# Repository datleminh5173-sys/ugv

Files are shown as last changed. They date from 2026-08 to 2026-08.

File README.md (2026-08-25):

# 🚜 BỘ THIẾT KẾ ROBOT UGV ĐA TẢI TRỌNG (UGV ROBOT PLATFORMS)

Kho lưu trữ thiết kế phần cứng, mô hình 3D (OpenSCAD, STL, 3MF) và tài liệu kỹ thuật cho các nền tảng xe tự hành mặt đất (**Unmanned Ground Vehicle - UGV**).

---

## 📂 CẤU TRÚC KHO LƯU TRỮ (REPOSITORY STRUCTURE)

```text
ugv/
├── 📁 ugv_jga25_v1/            # UGV JGA25 Bản V1 (Khung Liền Khối - In máy khổ lớn)
│   ├── 📁 SCAD/                # Mã nguồn mô hình OpenSCAD
│   ├── 📁 STL/                 # File STL sẵn sàng in 3D
│   ├── 📁 3MF/                 # File 3MF tối ưu slicer
│   └── 📄 README.md
│
├── 📁 ugv_jga25_v2/            # UGV JGA25 Bản V2 (Chia 5 Module ghép mộng mang cá - In vừa bàn 320x390)
│   ├── 📁 SCAD/                # File lắp ráp tổng thể V2 & chi tiết
│   ├── 📁 STL/                 # File STL in 3D
│   ├── 📁 3MF/                 # File 3MF tối ưu slicer
│   └── 📄 README.md
│
├── 📁 ugv_dc_150w/             # UGV Cỡ Trung (Động cơ DC ATS 150W cốt 12mm)
│   ├── 📁 SCAD/                # Bản vẽ 3D động cơ & Gá đỡ bắt đế
│   ├── 📁 images/              # Hình ảnh thực tế & kích thước kỹ thuật
│   └── 📄 THONG_SO_DONG_CO_ATS_150W.md
│
└── 📁 ugv_my1016z_250w/        # UGV Cỡ Lớn (Động cơ DC MY1016Z 250W - Nhông 9 răng)
    ├── 📁 SCAD/                # Bản vẽ 3D động cơ MY1016Z
    ├── 📁 images/              # Kích thước, sơ đồ chân & nhông xích
    ├── 📄 README.md            # Thông số vận hành & tỉ số truyền
    └── 📄 THONG_SO_DONG_CO_MY1016Z.md
```

---

## ⚡ SO SÁNH CÁC NỀN TẢNG (PLATFORM COMPARISON)

| Nền Tảng | Động Cơ | Tải Trọng | Đặc Điểm Thân Xe | Kích Thước Khung Xe | Bàn In Phù Hợp |
| :--- | :--- | :--- | :--- | :--- | :--- |
| **`ugv_jga25_v1`** | JGA25 (12V/24V) | $< 8\text{ kg}$ | **Liền khối nguyên bản** (Zero-Bolts) | $364 \times 320 \times 125\text{ mm}$ | Khổ lớn $\ge 400\text{mm}$ |
| **`ugv_jga25_v2`** | JGA25 (12V/24V) | $< 8\text{ kg}$ | **Chia 5 Module** (Mộng mang cá + Ốc M3) | Module lớn nhất $350 \times 140\text{ mm}$ | **Bàn in $320 \times 390\text{mm}$** hoặc $256\text{mm}$ |
| **`ugv_dc_150w`** | ATS 150W (Cốt 12mm) | $15 - 30\text{ kg}$ | Bắt đế cứng vững chịu lực cao | Thiết kế theo khung gầm xe tải trung | Mọi máy in 3D |
| **`ugv_my1016z_250w`** | MY1016Z 250W | $40 - 80\text{ kg}$ | Truyền động nhông xích 410 tải nặng | Thiết kế theo khung gầm xe tải nặng | Mọi máy in 3D |

---
*Bản quyền thiết kế © 2026 - Tác giả: datleminh5173-sys*

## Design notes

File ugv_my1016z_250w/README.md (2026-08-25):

# Dự Án UGV - Động Cơ Giảm Tốc DC MY1016Z / MY1016Z2 / MY1016Z3

Dự án thiết kế mô hình 3D OpenSCAD và tích hợp cụm dẫn động động cơ giảm tốc công suất cao **MY1016Z / MY1016Z2 / MY1016Z3** cho xe tự hành UGV / AGV / Robot địa hình.

Nguồn thông số chính hãng: **[TYHE Motors (www.tyhemotors.com/my1016z)](https://www.tyhemotors.com/my1016z)** & Bản vẽ thiết kế CAD 2D/3D.

## 1. Thư Viện Bản Vẽ Kỹ Thuật & Ảnh Thực Tế

### A. Ảnh & Bản vẽ từ TYHE Motors (`images/tyhe/`):
- [Ảnh 1: Góc nghiêng mặt trước](images/tyhe/TYHE_MY1016Z_01_Front_Angle.jpg)
- [Ảnh 2: Nhìn ngang thân & đế](images/tyhe/TYHE_MY1016Z_02_Side_View.jpg)
- [Ảnh 3: Nắp tản nhiệt sau & dây nguồn](images/tyhe/TYHE_MY1016Z_03_Rear_Angle.jpg)
- [Ảnh 4: Trục ra & nhông xích 9 răng](images/tyhe/TYHE_MY1016Z_04_Shaft_CloseUp.jpg)
- [Ảnh 5: Nhìn từ trên xuống](images/tyhe/TYHE_MY1016Z_05_Top_View.jpg)
- [Ảnh 6: Mặt đáy chân đế bắt sàn](images/tyhe/TYHE_MY1016Z_06_Bottom_Base.jpg)
- [Bản vẽ 7: Kích thước hình học TYHE](images/tyhe/TYHE_MY1016Z_07_Dimensional_Drawing.png)
- [Bản vẽ 8: Đặc tính động cơ & hộp số](images/tyhe/TYHE_MY1016Z_08_Motor_Drawing_Specs.png)

### B. Bản vẽ CAD 2D & Ảnh thực tế (`images/`):
- [Bản vẽ 1: Hình chiếu cạnh & Chân đế](images/04_Ban_Ve_Kich_Thuoc_Canh_Va_Chan_De.png)
- [Bản vẽ 2: Mặt trước hộp số & Tâm lỗ](images/05_Ban_Ve_Mat_Truoc_Va_Tam_Lo.png)
- [Bản vẽ 3: CAD chi tiết góc nghiêng 15°](images/08_Ban_Ve_CAD_Chi_Tiet_Goc_Nghieng_15Do.png)
- [Ảnh thực tế 1: Động cơ & nhông 9T](images/06_Anh_Thuc_Te_Goc_Nghieng_MY1016Z.png)
- [Ảnh thực tế 2: Tem nhãn thông số](images/07_Anh_Thuc_Te_Nhan_Thong_So.png)

## 2. Bảng Tóm Tắt Thông Số Kỹ Thuật

- **Điện áp**: 12V / 24V DC
- **Công suất**: 250W (thân dài $102\text{ mm}$, peak $300\text{W}$) / 350W (thân dài $117\text{ mm}$)
- **Tốc độ động cơ**: $2700 - 3300\text{ RPM}$
- **Tỷ số giảm tốc**: $9.78:1$ (hoặc $9:1$) $\rightarrow$ **Tốc độ đầu ra**: $\approx 300 - 330\text{ RPM}$
- **Mô-men xoắn**: $5.0 - 12.5\text{ N.m}$ ($50\text{ kg.cm}$)
- **Vật liệu**: Vỏ hợp kim kẽm (Zinc alloy), bánh răng thép tôi cứng (Steel gear), vòng bi cầu (Ball bearing)
- **Độ rơ bánh răng (Backlash)**: $\le 2^\circ$
- **Lực hướng kính / dọc trục tối đa**: $\le 5\text{ kgf}$ (Radial) / $\le 10\text{ kgf}$ (Axial) / $\le 20\text{ kgf}$ (Press)
- **Truyền động**: Nhông xích 9 răng, bước xích $12.7\text{ mm}$ (chuẩn xích #410 / xích xe đạp), đường kính con lăn $\varnothing 7.95\text{ mm}$
- **Khoảng cách tâm 2 trục**: $39\text{ mm}$ (tâm motor $\leftrightarrow$ tâm trục ra)
- **Đường kính thân motor**: $\varnothing 101\text{ mm}$
- **Chiều cao tâm trục**: $81 - 82\text{ mm}$ (tính từ đáy chân đế)
- **Khoảng cách lỗ chân đế**: $95 \pm 0.11\text{ mm} \times 42 \pm 0.08\text{ mm}$ (4 lỗ $\varnothing 6.5\text{ mm}$)

Chi tiết thông số xem tại: [THONG_SO_DONG_CO_MY1016Z.md](THONG_SO_DONG_CO_MY1016Z.md)

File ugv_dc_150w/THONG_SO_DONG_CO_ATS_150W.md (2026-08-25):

# Thông Số Kỹ Thuật & Kích Thước Lỗ Ốc Động Cơ ATS Motor (ZY6812 / MY6812) 12-24V 150W 7000RPM

---

## 1. Hình Ảnh Thực Tế & Bản Vẽ Kích Thước

| Ảnh 1: Thông số & Mặt trước Motor | Ảnh 2: Kích thước thân & Trục | Ảnh 3: Mặt trước 3 lỗ bắt ốc tam giác |
| :---: | :---: | :---: |
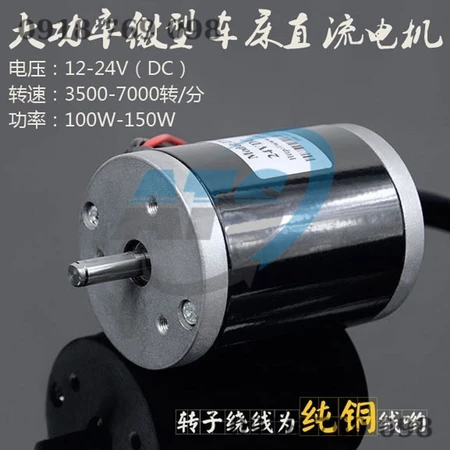
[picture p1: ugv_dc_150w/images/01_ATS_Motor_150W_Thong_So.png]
Thông số mặt trước
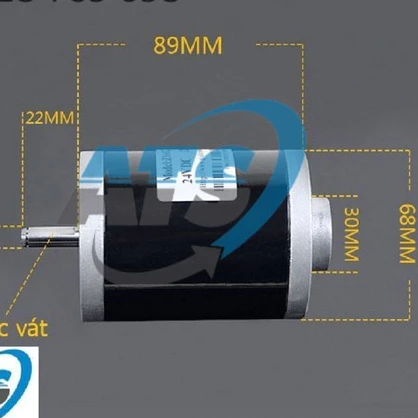
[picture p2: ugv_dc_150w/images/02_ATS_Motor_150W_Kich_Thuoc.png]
Kích thước thân
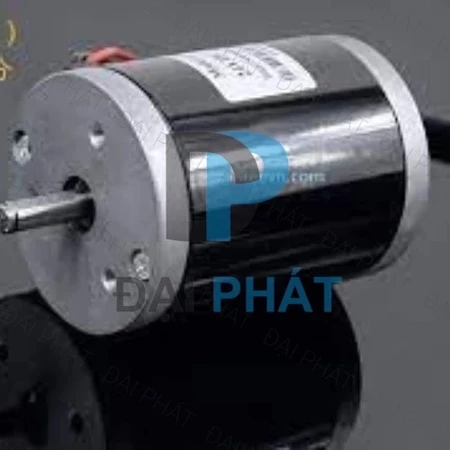
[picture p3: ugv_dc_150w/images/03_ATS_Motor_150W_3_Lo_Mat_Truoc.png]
3 Lỗ ốc mặt trước
|  |  |  |

---

## 2. Bảng Thông Số Điện - Cơ Học (Electrical & Mechanical Specs)

* **Tên thương mại:** Động cơ ATS Motor / Động cơ máy tiện mini DC / Động cơ ZY6812 (MY6812 / 68ZYT)
* **Loại động cơ:** Động cơ điện một chiều chổi than (Brushed DC Motor), nam châm vĩnh cửu
* **Rotor:** Cuộn dây đồng 100% (Pure copper winding)
* **Điện áp hoạt động:** DC $12\text{V} - 24\text{V}$
* **Công suất định mức:** $100\text{W} - 150\text{W}$ (Đạt cực đại $150\text{W}$ tại $24\text{V}$)
* **Tốc độ vòng tua (Speed):**
  * Tại $12\text{V}$: $\approx 3.500\text{ RPM}$
  * Tại $24\text{V}$: $\approx 7.000\text{ RPM}$ (Không tải có thể đạt $7.000 - 7.500\text{ RPM}$)
* **Dòng không tải (No-load Current):** $\approx 0.8\text{A} - 1.2\text{A}$
* **Dòng định mức (Rated Current):** $\approx 4.0\text{A} - 8.0\text{A}$
* **Dòng khởi động / Khóa trục (Stall Current):** $\approx 10\text{A} - 15\text{A}$ (Khuyến nghị dùng nguồn $24\text{V} \ge 10\text{A}$ hoặc ắc quy)
* **Hướng quay:** 2 chiều (Đảo chiều bằng cách đổi cực cấp nguồn $+/-$)
* **Trọng lượng:** $\approx 1.05\text{ kg} - 1.15\text{ kg}$

---

## 3. Kích Thước Hình Học Tổng Thể (Overall Dimensions)

| Bộ phận | Kích thước thực tế | Ghi chú |
| :--- | :---: | :--- |
| **Đường kính thân motor ($\varnothing D$)** | **$68\text{ mm}$** | Thân trụ tròn kim loại sơn đen bóng |
| **Chiều dài thân kim loại ($L_{body}$)** | **$89\text{ mm}$** | Phần thân chính giữa 2 nắp nhôm trước/sau |
| **Chiều dài tổng thể ($L_{total}$)** | **$\approx 115 - 120\text{ mm}$** | Bao gồm trục nhô phía trước và gờ đuôi sau |
| **Đường kính trục ($\varnothing d_{shaft}$)** | **$\varnothing 8\text{ mm}$** | Trục thép chuẩn $\varnothing 8\text{ mm}$ |
| **Chiều dài trục nhô ra ($L_{shaft}$)** | **$22\text{ mm}$** | Đo từ mặt bích nhôm trước ra đầu trục |
| **Kiểu trục (Shaft Type)** | **Trục vát phẳng D (D-Cut Shaft)** | Chiều dày sau vát $\approx 7.2 - 7.5\text{ mm}$, tiện lắp ốc chí puly/khớp nối |
| **Gờ định vị đuôi sau (Rear Boss)** | **$\varnothing 30\text{ mm}$**, nhô **$4 - 6\text{ mm}$** | Nắp ổ đỡ bạc đạn sau |
| **Gờ định vị mặt trước (Front Boss)** | **$\varnothing 28 - 30\text{ mm}$**, nhô **$\approx 3 - 4\text{ mm}$** | Gờ định vị tâm ổ bi trước |

---

## 4. CHI TIẾT KÍCH THƯỚC 3 LỖ VẶN VÍT MẶT BÍCH (3-Hole Triangle Mounting Pattern)

Theo bản vẽ kỹ thuật chuẩn quốc tế của dòng motor 6812 (MY6812/ZY6812) và hình ảnh thực tế từ xưởng Đại Phát / ATS:

```
                            [ Lỗ Ren 1 (90° - Đỉnh trên) ]
                                         ●
                                       /   \
                                      /  ○  \   (Trục Ø8mm + Gờ Ø29.5mm)
           Khoảng cách cạnh: 35.6mm  /   |   \  Khoảng cách cạnh: 35.6mm
                                    /    R    \
                                   /     |     \
                                  ● ----------- ●
             [ Lỗ Ren 2 (210° - Dưới trái) ]    [ Lỗ Ren 3 (330° - Dưới phải) ]
                                   Khoảng cách đáy: 35.6mm
```

### 4.1. Thông số hình học 3 lỗ bắt ốc:
1. **Số lượng lỗ bắt vít:** **3 lỗ ren M5** bố trí dạng **tam giác đều cách nhau $120^\circ$**.
2. **Kích thước ren (Thread Size):** **Ren M5** (bước ren tiêu chuẩn $M5 \times 0.8\text{ mm}$).
   * Độ sâu ren: $\approx 6\text{ mm} - 8\text{ mm}$.
3. **Khoảng cách giữa các lỗ (Center-to-Center Pitch):**
   * **Khoảng cách thẳng giữa 2 lỗ cạnh nhau (cạnh tam giác $a$):** **$35.6\text{ mm}$** (tương đương $1.4\text{ inch}$).
   * **Đường kính vòng chia tâm lỗ (Pitch Circle Diameter - PCD):**
     $$\text{PCD} = \frac{2a}{\sqrt{3}} = \frac{2 \times 35.6}{1.732} \approx \mathbf{41.1\text{ mm}} \quad (\text{Bán kính từ tâm trục } R \approx \mathbf{20.5\text{ mm}})$$
4. **Tọa độ tâm 3 lỗ ốc (Gốc $(0,0)$ tại tâm trục động cơ):**
   * **Lỗ 1 (Đỉnh trên $90^\circ$):** $(X = 0,\ Y = +20.5\text{ mm})$
   * **Lỗ 2 (Dưới - Trái $210^\circ$):** $(X = -17.8\text{ mm},\ Y = -10.25\text{ mm})$
   * **Lỗ 3 (Dưới - Phải $330^\circ$):** $(X = +17.8\text{ mm},\ Y = -10.25\text{ mm})$

---

## 5. Khuyến Nghị Khi Thiết Kế Gá Đỡ / Pat Bắt Động Cơ 3 Lỗ (Bracket Design Tips)

1. **Làm 3 rãnh hạt đậu (Slotted Holes):**
   * Bố trí 3 rãnh ở 3 góc $90^\circ, 210^\circ, 330^\circ$.
   * Chiều rộng rãnh: $\varnothing 5.5\text{ mm}$ (dễ dàng xỏ ốc M5).
   * Bán kính rãnh: Kéo dài từ $R = 18.0\text{ mm} \rightarrow R = 22.0\text{ mm}$ (PCD từ $36\text{ mm} \rightarrow 44\text{ mm}$) để triệt tiêu mọi sai số gia công giữa các xưởng OEM.
2. **Lỗ thoát gờ tâm (Center Pilot Hole):** Khoét lỗ tròn đường kính **$\varnothing 31\text{ mm}$** để lọt hoàn toàn gờ bạc đạn mặt trước ($\varnothing 29.5\text{ mm}$).
3. **Chiều dài bu-lông M5:** Dùng bu-lông M5 dài $10 - 12\text{ mm}$ (kèm long đen vênh chống trôi ốc do rung động động cơ).

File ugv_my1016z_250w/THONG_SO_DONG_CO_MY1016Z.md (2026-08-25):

# THÔNG SỐ KỸ THUẬT ĐỘNG CƠ GIẢM TỐC DC MY1016Z / MY1016Z2 / MY1016Z3
## (Nguồn trích xuất: TYHE Motors & Nhà Sản Xuất - 12V/24V 250W/350W)

Tài liệu kỹ thuật tổng hợp chi tiết thông số điện, cơ lý tính, giới hạn tải trọng, vật liệu chế tạo và kích thước hình học 2D/3D từ catalog chính hãng **[TYHE Motors (www.tyhemotors.com/my1016z)](https://www.tyhemotors.com/my1016z)** cùng bản vẽ thiết kế CAD chế tạo.

---

## 1. Bảng Thông Số Điện & Hiệu Năng Động Cơ (Electrical & Output Specs)

| Thông Số (Parameters) | MY1016Z (12V 250W) | MY1016Z2 (24V 250W - TYHE) | MY1016Z3 (24V 350W) | Đơn Vị | Ghi Chú |
| :--- | :--- | :--- | :--- | :--- | :--- |
| **Nhà sản xuất / Tiêu chuẩn** | Standard OEM / CE | **TYHE Motors Manufacturer** | Standard OEM / CE | - | Động cơ DC chổi than nam châm vĩnh cửu |
| **Điện áp định mức (Rated Voltage)** | **12** | **24** | **24** (hoặc 36V) | V DC | Tương thích Ắc quy / LiFePO4 / Li-ion |
| **Công suất đầu ra (Rated Output)** | **250** | **250** (Peak 300W) | **350** | W | Công suất cơ tại trục hộp số |
| **Dòng điện định mức (Rated Current)** | **≤ 14.0** (~13.5) | **≤ 13.4** | **18.7** | A | Dòng tiêu thụ khi đủ tải |
| **Dòng không tải (No-load Current)** | **≤ 2.0** | **≤ 1.5** | **≤ 2.0** | A | Dòng khi quay tự do |
| **Tốc độ định mức motor (Base Speed)**| **2700 - 3000** | **3000 - 3300** | **2800 - 3300** | RPM | Tốc độ trước khi qua hộp số |
| **Tỷ số giảm tốc (Gear Ratio)** | **9:1** | **9.78:1** (TYHE Spec) | **9.78:1** | - | Hộp số bánh răng thép chịu tải lớn |
| **Tốc độ trục ra (Output Speed)** | **~ 300** | **~ 300 - 330** | **~ 300 - 330** | RPM | Tốc độ quay của nhông xích đầu ra |
| **Mô-men xoắn định mức (Rated Torque)**| **~ 8.5 - 9.5** | **5.0 - 9.5** ($50\text{ kg.cm}$) | **~ 11.0 - 12.5** | N.m | Lực kéo cực khỏe chuyên dùng cho UGV/AGV |
| **Hiệu suất động cơ (Efficiency)** | **≥ 78%** | **≥ 78%** | **≥ 78%** | - | Tiết kiệm điện năng hệ thống UGV |
| **Trọng lượng (Weight)** | **~ 2.3** | **~ 2.3** | **~ 2.6** | kg | Toàn bộ cụm motor + hộp số + chân đế |

---

## 2. Đặc Tính Cơ Lý & Giới Hạn Tải Trọng (Mechanical & Physical Characteristics - TYHE)

| Tiêu Chí Kỹ Thuật (Specification) | Giá Trị (Values) | Đơn Vị / Chuẩn | Ý Nghĩa Kỹ Thuật Khi Thiết Kế UGV |
| :--- | :--- | :--- | :--- |
| **Vật liệu vỏ mặt gá (Housing Material)**| **Hợp kim kẽm đúc (Zinc alloy)** | Die-cast alloy | Chống ăn mòn, chịu va đập cơ học tốt |
| **Vật liệu bánh răng (Gear Material)** | **Thép hợp kim tôi cứng (Steel)** | Hardened Steel | Chịu lực xoắn và chống mài mòn cao |
| **Độ rơ bánh răng (Backlash)** | **$\le 2^\circ$** | Độ góc | Độ chính xác cao cho điều khiển xe tự hành |
| **Loại ổ đỡ trục ra (Output Bearing)** | **Vòng bi cầu (Ball bearing)** | Deep groove | Chịu tải trọng hướng kính tốt, quay êm |
| **Tốc độ đầu vào tối đa khuyến nghị** | **$\le 4000$** | RPM | Giới hạn an toàn chống quá nhiệt hộp số |
| **Lực hướng kính tối đa (Radial Force)**| **$\le 5$** | kgf | Giới hạn lực căng xích tì ngang lên trục |
| **Lực dọc trục tối đa (Axial Force)** | **$\le 10$** | kgf | Giới hạn lực đẩy/kéo dọc theo trục |
| **Lực ép/nhấn tối đa (Max Press Force)**| **$\le 20$** | kgf | Lực tối đa khi ép nhông/khóa then vào trục |
| **Độ rơ hướng kính (Radial Clearance)** | **$\le 0.1$** | mm | Khe hở lắc ngang trục cực nhỏ |
| **Độ rơ dọc trục (Axial Clearance)** | **$\le 0.3$** | mm | Khe hở trượt dọc trục |
| **Nhiệt độ làm việc (Operating Temp)** | **$-20^\circ\text{C} \sim 120^\circ\text{C}$** | $^\circ\text{C}$ | Chịu nhiệt dải rộng cho môi trường ngoài trời |
| **Độ ồn hoạt động (Noise Level)** | **$\le 70$** | dB | Vận hành êm ái |
| **Cổ góp / Chổi than (Commutator)** | **Chổi than (Brushed)** | Carbon brush | Dễ bảo dưỡng, khởi động mô-men lớn |
| **Chiều quay (Direction of Rotation)** | **CW / CCW (Đảo chiều)** | 2 chiều | Đảo cực $\pm$ nguồn điện để lùi/tiến xe |

---

## 3. Bảng Dữ Liệu Động Cơ Lõi DC RS775 & Hộp Số Đa Cấp (TYHE Datasheet)

### 3.1. Thông Số Lõi Động Cơ DC (Motor Core RS775 Data)
| Cấu Hình Lõi | Điện Áp (V) | Không Tải: Vòng/phút (RPM) | Không Tải: Dòng (mA) | Định Mức: Vòng/phút (RPM) | Định Mức: Dòng (A) | Định Mức: Lực (mN.m) | Công Suất Ra (W) | Hiệu Suất (%) | Stall: Lực (mN.m) | Stall: Dòng (A) |
| :--- | :---: | :---: | :---: | :---: | :---: | :---: | :---: | :---: | :---: | :---: |
| **RS775-12V** | 12 | 7000 | 760 | 5600 | 2.81 | 38.00 | 22.28 | 66.16 | 114.00 | 20.00 |
| **RS775-24V** | 24 | 6500 | 395 | 5200 | 1.45 | 41.00 | 22.32 | 64.11 | 123.00 | 10.30 |

### 3.2. Dải Tỷ Số Truyền Hộp Số Phẳng $103 \times 60\text{ mm}$ (Gearbox Ratios)
- **Cấp 3 tầng bánh răng (3 Stages - Hiệu suất 61%)**: $26:1,\ 32:1,\ 33:1,\ 48:1,\ 57.7:1,\ 59:1$
- **Cấp 4 tầng bánh răng (4 Stages - Hiệu suất 52%)**: $132:1,\ 196:1,\ 246:1,\ 380:1$
- **Cấu hình truyền động tải nặng MY1016Z**: Tỷ số $9.78:1$ / $9:1$ bánh răng thép chuyên dụng truyền lực nhông xích.

---

## 4. Kích Thước Hình Học Chuẩn Theo Bản Vẽ Chế Tạo

*(Dữ liệu trích xuất từ bản vẽ CAD 2D & Catalog TYHE)*

| Bộ Phận | Kích Thước | Dung Sai | Ghi Chú Chi Tiết |
| :--- | :--- | :--- | :--- |
| **Chiều dài thân động cơ (A)** | **102 mm** (250W)<br>**117 mm** (350W) | $\pm 1\text{ mm}$ | Chiều dài từ mặt sau hộp số đến nắp sau |
| **Đường kính thân motor** | **Ø 101 mm** | $-0.20\text{ mm}$ | Vỏ thép trụ tròn sơn tĩnh điện đen |
| **Đường kính vành gân tản nhiệt sau** | **Ø 87 mm** | $\pm 0.5\text{ mm}$ | Nắp nhôm sau có gân |
| **Đường kính ngoài bầu hộp số dưới** | **Ø 82 mm** | $+0 / -0.25\text{ mm}$ | Phần chứa trục ra |
| **Khoảng cách 2 tâm trục (Center Distance)**| **39 mm** | $\pm 0.1\text{ mm}$ | Tâm trục motor $\leftrightarrow$ tâm trục ra |
| **Bề dày hộp số nhôm đúc** | **22.5 mm** | $\pm 0.3\text{ mm}$ | Chiều dày phần vỏ hộp số |
| **Gờ đỡ ổ bi moay-ơ (Hub Protrusion)** | **19.5 mm** / **Ø 36 mm** | - | Ống trụ nhô quanh trục nhông |
| **Mặt phẳng nhông $\leftrightarrow$ Tâm đế** | **50 mm** | $\pm 1.0\text{ mm}$ | Cự ly từ mặt nhông xích đến tâm hàng ốc đế |
| **Chiều cao tâm trục ra đến đáy đế** | **81 - 82 mm** | $\pm 0.5\text{ mm}$ | Chiều cao từ tâm nhông xuống sàn gá |
| **Kích thước bao đường chéo lớn nhất** | **128 mm** | - | Đường kính bao phủ bì mặt trước |

### Thông Số Nhông Xích 9 Răng:
- **Số răng**: **9 răng (9T)**
- **Bước xích (Pitch)**: **12.7 mm** (Chuẩn xích $1/2\text{ inch}$ / Xích xe đạp standard / Xích công nghiệp #410)
- **Đường kính con lăn xích (Roller O.D.)**: **Ø 7.95 mm**
- **Độ dày bản răng (Tooth Thickness)**: **3.0 mm** (phần thân dày 5.5 mm)

### Kích Thước Lỗ Bắt Ốc & Gá Lắp:
1. **Mặt bích trước (3 lỗ ren M6)**: Bố trí nghiêng góc **$15^\circ$**, khoảng cách tâm lỗ **$58\text{ mm}, 85\text{ mm}, 108\text{ mm}$**, độ sâu ren $\approx 9.5\text{ mm}$.
2. **Chân đế bắt đáy (4 lỗ Ø 6.5 mm)**: Tâm lỗ dọc **$95 \pm 0.11\text{ mm}$**, tâm lỗ ngang **$42 \pm 0.08\text{ mm}$**, bề rộng chân đế **$55\text{ mm}$**, khoét eo **$38\text{ mm}$**.

---

## 5. Thư Viện Hình Ảnh & Bản Vẽ Kỹ Thuật Đầy Đủ

### A. Thư viện hình ảnh từ [TYHE Motors](https://www.tyhemotors.com/my1016z):
Thư mục: [`images/tyhe/`](file:///c:/test/ugv%20Motor%20Gi%E1%BA%A3m%20T%E1%BB%91c%20DC%2012v%20250w%20MY1016Z%209%20r%C4%83ng/images/tyhe)

1. [TYHE_MY1016Z_01_Front_Angle.jpg](file:///c:/test/ugv%20Motor%20Gi%E1%BA%A3m%20T%E1%BB%91c%20DC%2012v%20250w%20MY1016Z%209%20r%C4%83ng/images/tyhe/TYHE_MY1016Z_01_Front_Angle.jpg) — *Ảnh chụp góc nghiêng mặt trước hộp số nhôm & nhông xích.*
2. [TYHE_MY1016Z_02_Side_View.jpg](file:///c:/test/ugv%20Motor%20Gi%E1%BA%A3m%20T%E1%BB%91c%20DC%2012v%20250w%20MY1016Z%209%20r%C4%83ng/images/tyhe/TYHE_MY1016Z_02_Side_View.jpg) — *Ảnh chụp góc nhìn ngang thân động cơ và chân đế.*
3. [TYHE_MY1016Z_03_Rear_Angle.jpg](file:///c:/test/ugv%20Motor%20Gi%E1%BA%A3m%20T%E1%BB%91c%20DC%2012v%20250w%20MY1016Z%209%20r%C4%83ng/images/tyhe/TYHE_MY1016Z_03_Rear_Angle.jpg) — *Ảnh chụp nắp nhôm tản nhiệt phía sau & dây nguồn.*
4. [TYHE_MY1016Z_04_Shaft_CloseUp.jpg](file:///c:/test/ugv%20Motor%20Gi%E1%BA%A3m%20T%E1%BB%91c%20DC%2012v%20250w%20MY1016Z%209%20r%C4%83ng/images/tyhe/TYHE_MY1016Z_04_Shaft_CloseUp.jpg) — *Ảnh chụp cận cảnh cụm trục ra, nhông 9 răng và đai ốc khóa.*
5. [TYHE_MY1016Z_05_Top_View.jpg](file:///c:/test/ugv%20Motor%20Gi%E1%BA%A3m%20T%E1%BB%91c%20DC%2012v%20250w%20MY1016Z%209%20r%C4%83ng/images/tyhe/TYHE_MY1016Z_05_Top_View.jpg) — *Ảnh chụp nhìn từ trên xuống.*
6. [TYHE_MY1016Z_06_Bottom_Base.jpg](file:///c:/test/ugv%20Motor%20Gi%E1%BA%A3m%20T%E1%BB%91c%20DC%2012v%20250w%20MY1016Z%209%20r%C4%83ng/images/tyhe/TYHE_MY1016Z_06_Bottom_Base.jpg) — *Ảnh chụp mặt đáy chân gá bắt sàn xe.*
7. [TYHE_MY1016Z_07_Dimensional_Drawing.png](file:///c:/test/ugv%20Motor%20Gi%E1%BA%A3m%20T%E1%BB%91c%20DC%2012v%20250w%20MY1016Z%209%20r%C4%83ng/images/tyhe/TYHE_MY1016Z_07_Dimensional_Drawing.png) — *Bản vẽ kích thước hình học từ catalog TYHE.*
8. [TYHE_MY1016Z_08_Motor_Drawing_Specs.png](file:///c:/test/ugv%20Motor%20Gi%E1%BA%A3m%20T%E1%BB%91c%20DC%2012v%20250w%20MY1016Z%209%20r%C4%83ng/images/tyhe/TYHE_MY1016Z_08_Motor_Drawing_Specs.png) — *Bảng thông số & biểu đồ đặc tính TYHE.*

### B. Thư viện bản vẽ CAD 2D & Hình ảnh gốc:
Thư mục: [`images/`](file:///c:/test/ugv%20Motor%20Gi%E1%BA%A3m%20T%E1%BB%91c%20DC%2012v%20250w%20MY1016Z%209%20r%C4%83ng/images)

1. [04_Ban_Ve_Kich_Thuoc_Canh_Va_Chan_De.png](file:///c:/test/ugv%20Motor%20Gi%E1%BA%A3m%20T%E1%BB%91c%20DC%2012v%20250w%20MY1016Z%209%20r%C4%83ng/images/04_Ban_Ve_Kich_Thuoc_Canh_Va_Chan_De.png) — *Bản vẽ hình chiếu cạnh & đáy chân đế ($95\text{ mm} \times 42\text{ mm}$, nhông 9T pitch 12.7).*
2. [05_Ban_Ve_Mat_Truoc_Va_Tam_Lo.png](file:///c:/test/ugv%20Motor%20Gi%E1%BA%A3m%20T%E1%BB%91c%20DC%2012v%20250w%20MY1016Z%209%20r%C4%83ng/images/05_Ban_Ve_Mat_Truoc_Va_Tam_Lo.png) — *Bản vẽ mặt trước hộp số, khoảng cách tâm 2 trục $39\text{ mm}$, đường kính Ø101, Ø87, Ø82, Note A 102/117mm.*
3. [08_Ban_Ve_CAD_Chi_Tiet_Goc_Nghieng_15Do.png](file:///c:/test/ugv%20Motor%20Gi%E1%BA%A3m%20T%E1%BB%91c%20DC%2012v%20250w%20MY1016Z%209%20r%C4%83ng/images/08_Ban_Ve_CAD_Chi_Tiet_Goc_Nghieng_15Do.png) — *Bản vẽ CAD góc nghiêng 15 độ của các lỗ ốc M6 mặt bích.*
4. [06_Anh_Thuc_Te_Goc_Nghieng_MY1016Z.png](file:///c:/test/ugv%20Motor%20Gi%E1%BA%A3m%20T%E1%BB%91c%20DC%2012v%20250w%20MY1016Z%209%20r%C4%83ng/images/06_Anh_Thuc_Te_Goc_Nghieng_MY1016Z.png) — *Ảnh chụp góc nghiêng chi tiết động cơ thực tế.*
5. [07_Anh_Thuc_Te_Nhan_Thong_So.png](file:///c:/test/ugv%20Motor%20Gi%E1%BA%A3m%20T%E1%BB%91c%20DC%2012v%20250w%20MY1016Z%209%20r%C4%83ng/images/07_Anh_Thuc_Te_Nhan_Thong_So.png) — *Ảnh tem nhãn thông số thực tế.*
6. [01_MY1016Z_Thong_So_Tong_Quan.png](file:///c:/test/ugv%20Motor%20Gi%E1%BA%A3m%20T%E1%BB%91c%20DC%2012v%20250w%20MY1016Z%209%20r%C4%83ng/images/01_MY1016Z_Thong_So_Tong_Quan.png) — *Bảng thông số nhà sản xuất.*
7. [02_MY1016Z_Kich_Thuoc_Co_Khi.png](file:///c:/test/ugv%20Motor%20Gi%E1%BA%A3m%20T%E1%BB%91c%20DC%2012v%20250w%20MY1016Z%209%20r%C4%83ng/images/02_MY1016Z_Kich_Thuoc_Co_Khi.png) — *Kích thước cơ khí tổng quát.*
8. [03_MY1016Z_Chan_De_Va_Bat_Ga.png](file:///c:/test/ugv%20Motor%20Gi%E1%BA%A3m%20T%E1%BB%91c%20DC%2012v%20250w%20MY1016Z%209%20r%C4%83ng/images/03_MY1016Z_Chan_De_Va_Bat_Ga.png) — *Kích thước chân đế và bát gá.*

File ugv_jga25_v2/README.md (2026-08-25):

# 🚀 UGV JGA25 (BẢN V2 - CHIA MODULE IN VỪA BÀN 320x390)

Phiên bản nâng cấp V2 chia nhỏ thân xe thành **5 Module độc lập** ghép nối bằng cơ cấu **Mộng Mang Cá Đứng (Dovetails)** và **Mặt bích khóa hốc tán lục giác M3 âm chìm (Captive Nut Flanges)**.

---

## 📂 CẤU TRÚC THƯ MỤC
```text
ugv_jga25_v2/
├── 📁 SCAD/          # File lắp ráp tổng thể V2 (00_UGV_Lap_Rap_Tong_The_v2.scad) & các chi tiết
├── 📁 STL/           # File STL in 3D
├── 📁 3MF/           # File 3MF tối ưu slicer
└── 📄 README.md
```

## 🧩 5 MODULE THÂN XE IN TÁCH RỜI
1. **Module 1 - Khoang Bụng Trung Tâm (Central Belly):** $350 \times 140 \times 109\text{ mm}$ (Màu Xám Đen). Tích hợp khay pin Li-Po/18650 có rãnh dây đai Velcro và 4 mộng mang cá đực.
2. **Module 2 - Mũi Trước & 2 Tháp Treo Trước (Front Bay):** $176 \times 95 \times 109\text{ mm}$ (Màu Cam). Tích hợp 2 rãnh âm mang cá + 4 lỗ ốc M3 liên kết.
3. **Module 3 - Đuôi Sau & 2 Tháp Treo Sau (Rear Bay):** $176 \times 95 \times 109\text{ mm}$ (Màu Cam). Tích hợp 2 rãnh âm mang cá + 4 lỗ ốc M3 liên kết.
4. **Module 4 - 4 Tấm Vè Giáp Nóc Hông (Fender Decks):** $105 \times 94 \times 42\text{ mm}$ (Màu Gunmetal). Gài rãnh trượt Clip-on.
5. **Module 5 - Nắp Nóc Xe Mở Bản Lề (Canopy Roof Lid):** $350 \times 320 \times 15\text{ mm}$ (Màu Xám Titan + SUMO V2).

## 🔩 CƠ CẤU LẮP GHÉP CƠ KHÍ
- **Mộng mang cá đứng góc $60^\circ$:** Chịu lực cắt, triệt tiêu hoàn toàn độ xê dịch và chống vặn xoắn khi xe vận hành.
- **8 Hốc tán lục giác M3 âm chìm:** Khóa chặt 8 bulông M3 từ 2 đầu mũi và đuôi xe.
- **Phù hợp bàn in:** In vừa vặn trên mọi máy in 3D khổ $320 \times 390\text{ mm}$, $300 \times 300\text{ mm}$ hoặc $256 \times 256\text{ mm}$.

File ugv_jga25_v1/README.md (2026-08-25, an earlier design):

# 🤖 UGV JGA25 (BẢN V1 - KHUNG LIỀN KHỐI MONOLITHIC)

Phiên bản thiết kế robot xe tự hành 4WD dùng động cơ JGA25 với thân xe nguyên khối đúc liền (Zero-Bolts / Không dùng ốc vít).

---

## 📂 CẤU TRÚC THƯ MỤC
```text
ugv_jga25_v1/
├── 📁 SCAD/          # File mã nguồn OpenSCAD (00 đến 08)
├── 📁 STL/           # File STL sẵn sàng in 3D
├── 📁 3MF/           # File 3MF tối ưu slicer
└── 📄 README.md
```

## 🛠️ ĐẶC ĐIỂM KỸ THUẬT BẢN V1
- **Khung gầm liền khối:** Toàn bộ thùng xe, 4 tháp gá treo và 4 vè chắn bùn đúc liền 1 khối.
- **Kích thước bao:** $364\text{ mm} \times 320\text{ mm} \times 125\text{ mm}$.
- **Yêu cầu máy in 3D:** Khuyến nghị máy in khổ lớn ($> 400\text{ mm}$) để in trọn vẹn thân xe 1 lần.
- **Hệ thống treo:** 4 Cụm treo độc lập khớp cầu Snap-fit tháo lắp nhanh.

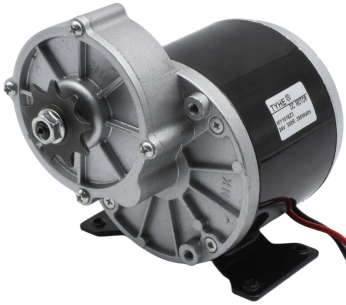
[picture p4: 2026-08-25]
ugv_my1016z_250w/images/tyhe/TYHE_MY1016Z_08_Motor_Drawing_Specs.png

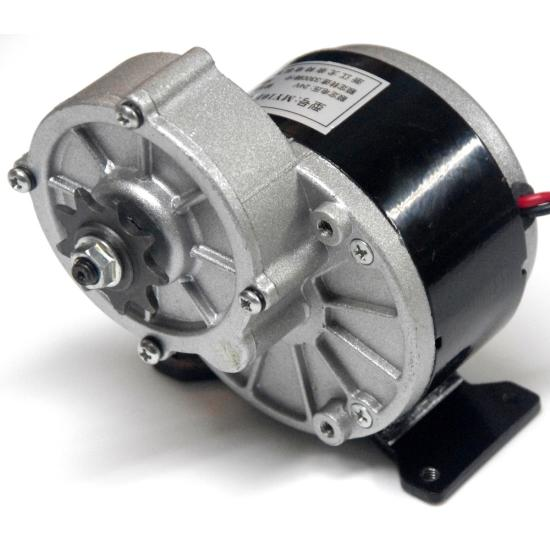
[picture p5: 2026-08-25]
ugv_my1016z_250w/images/06_Anh_Thuc_Te_Goc_Nghieng_MY1016Z.png

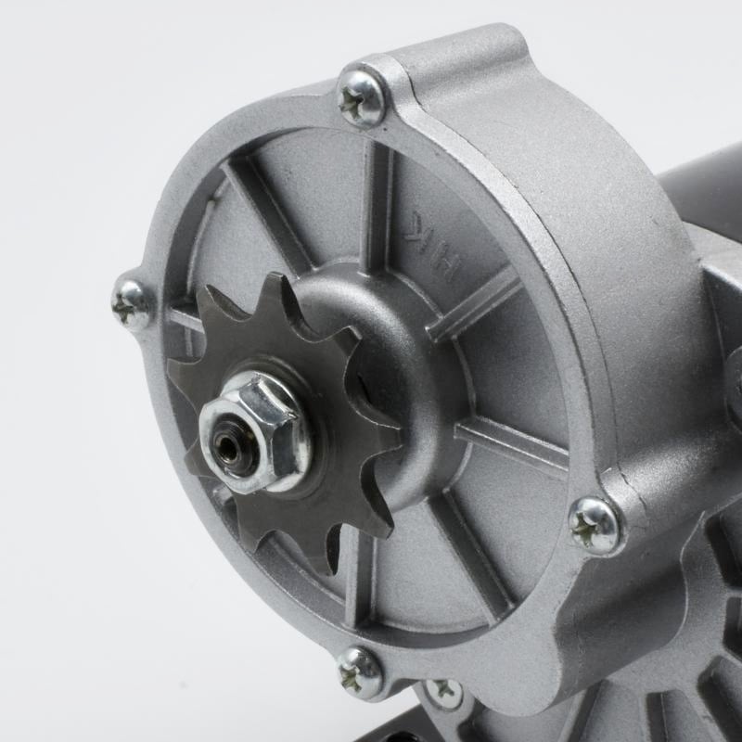
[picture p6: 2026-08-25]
ugv_my1016z_250w/images/tyhe/TYHE_MY1016Z_06_Bottom_Base.jpg

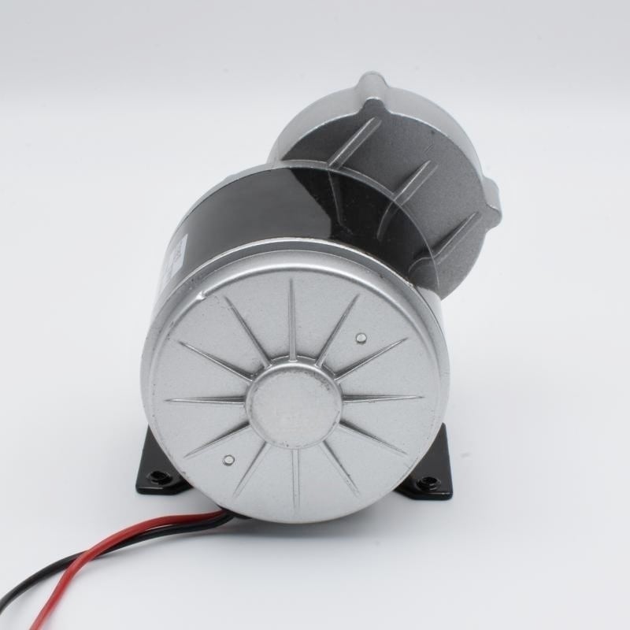
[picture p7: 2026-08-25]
ugv_my1016z_250w/images/tyhe/TYHE_MY1016Z_04_Shaft_CloseUp.jpg

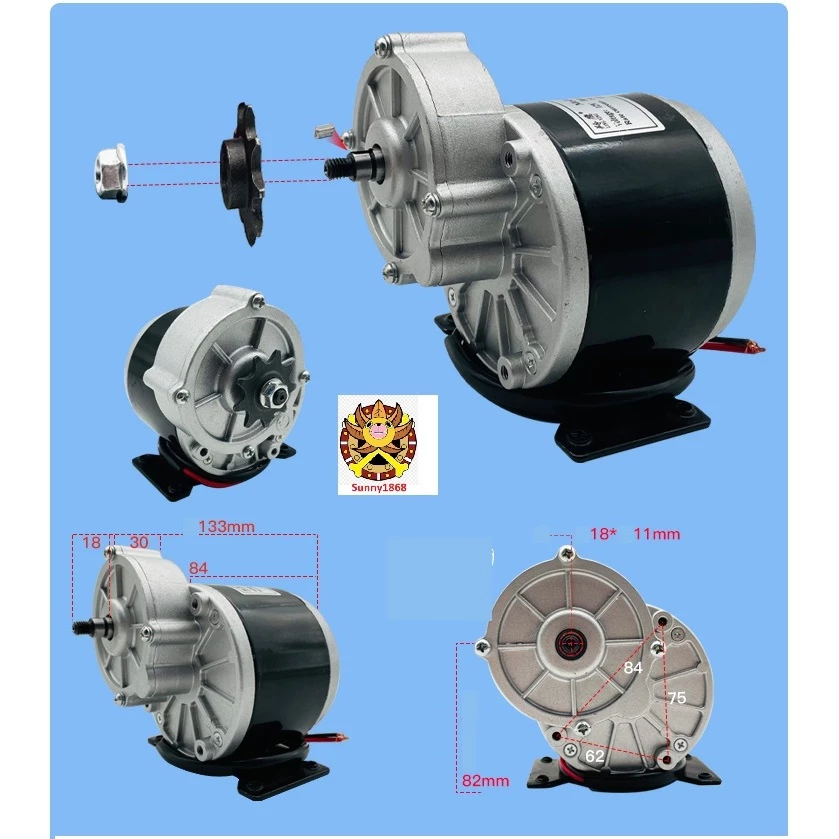
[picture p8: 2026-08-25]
ugv_my1016z_250w/images/02_MY1016Z_Kich_Thuoc_Co_Khi.png

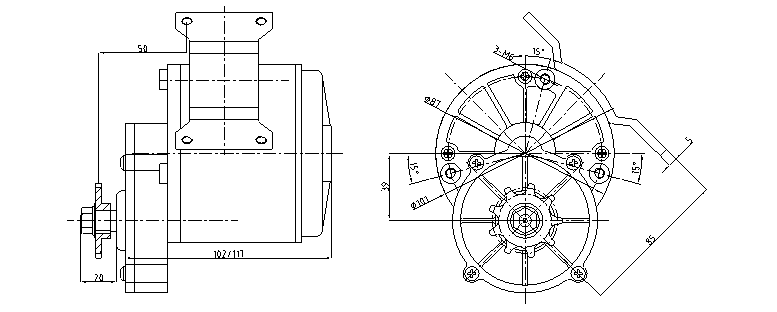
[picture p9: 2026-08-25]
ugv_my1016z_250w/images/tyhe/TYHE_MY1016Z_07_Dimensional_Drawing.png

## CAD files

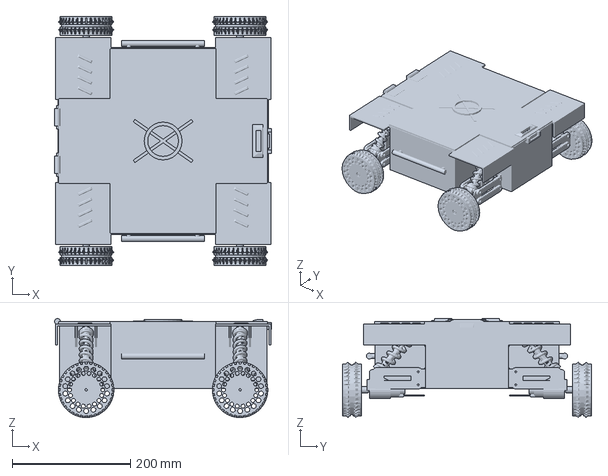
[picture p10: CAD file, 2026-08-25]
ugv_jga25_v2/3MF/00_UGV_Lap_Rap_Tong_The_Full_Xe.3mf
366.5 x 421.0 x 167.3 mm

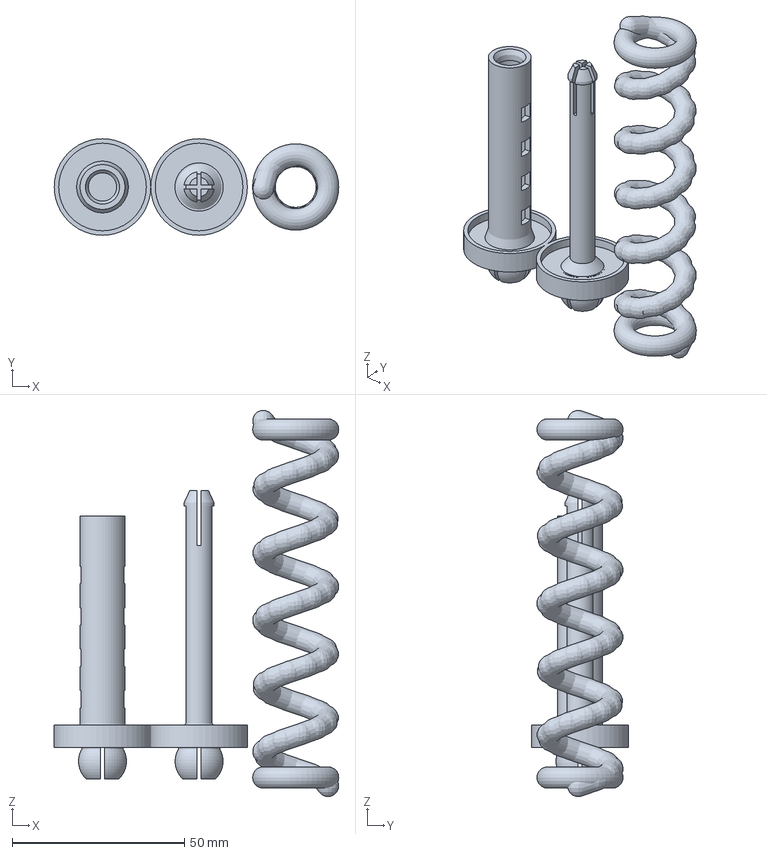
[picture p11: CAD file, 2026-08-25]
ugv_jga25_v2/3MF/06_Phuoc_Giam_Xoc.3mf
82.5 x 28.0 x 111.9 mm

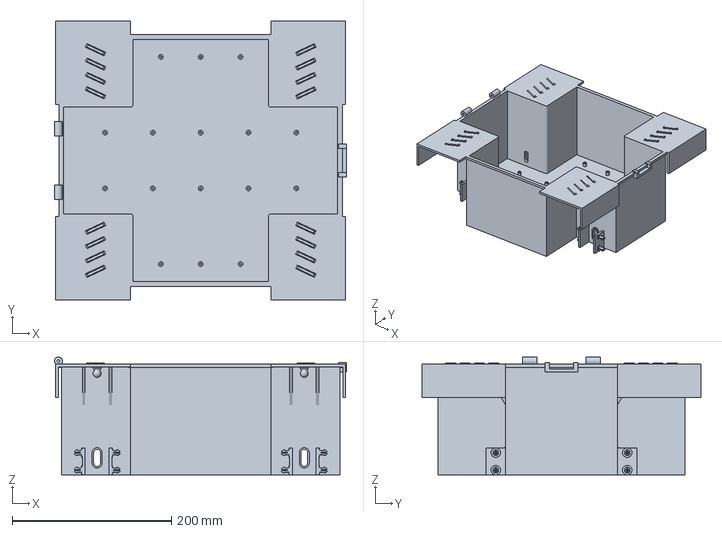
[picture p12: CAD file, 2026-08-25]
ugv_jga25_v2/3MF/01_Khung_Than_Xe_Lien_Khoi.3mf
366.5 x 350.0 x 148.0 mm

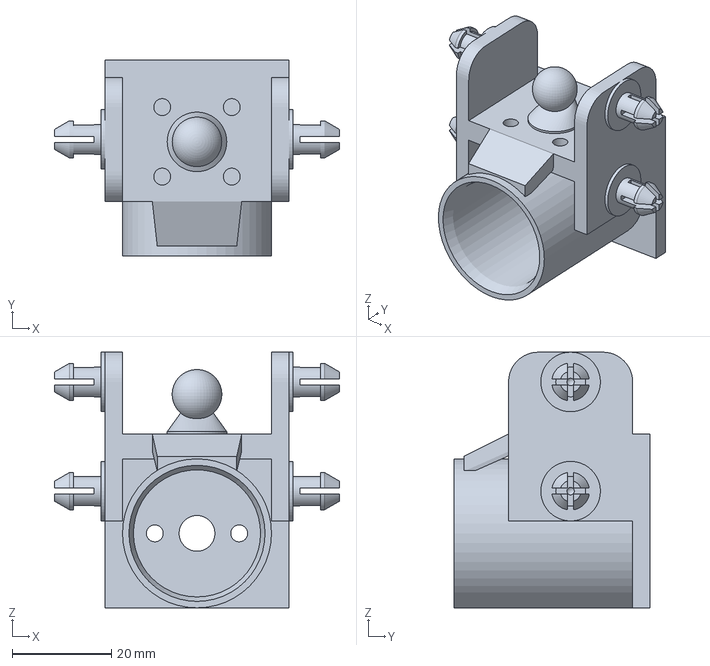
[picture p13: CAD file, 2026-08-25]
ugv_jga25_v2/3MF/03_Ga_Do_Dong_Co.3mf
57.4 x 39.5 x 51.5 mm

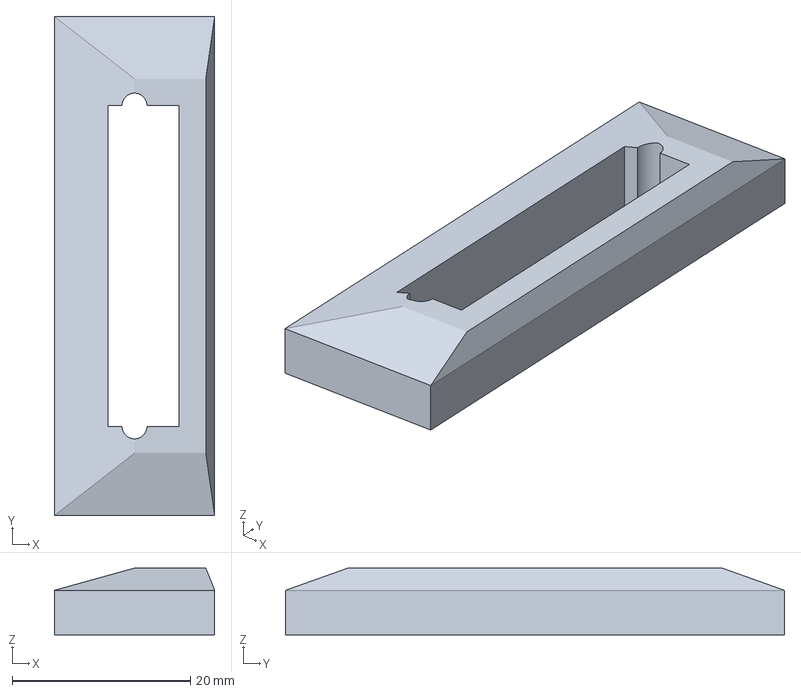
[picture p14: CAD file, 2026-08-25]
ugv_jga25_v2/3MF/07_Tay_Nam_Nap_Noc.3mf
18.0 x 56.0 x 7.50 mm

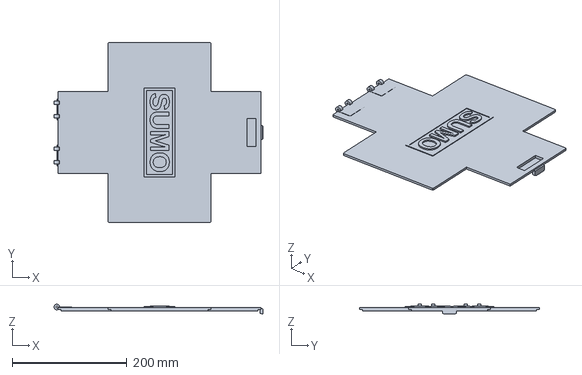
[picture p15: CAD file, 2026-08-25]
ugv_jga25_v2/3MF/02_Nap_Noc_Xe.3mf
363.5 x 313.0 x 17.0 mm

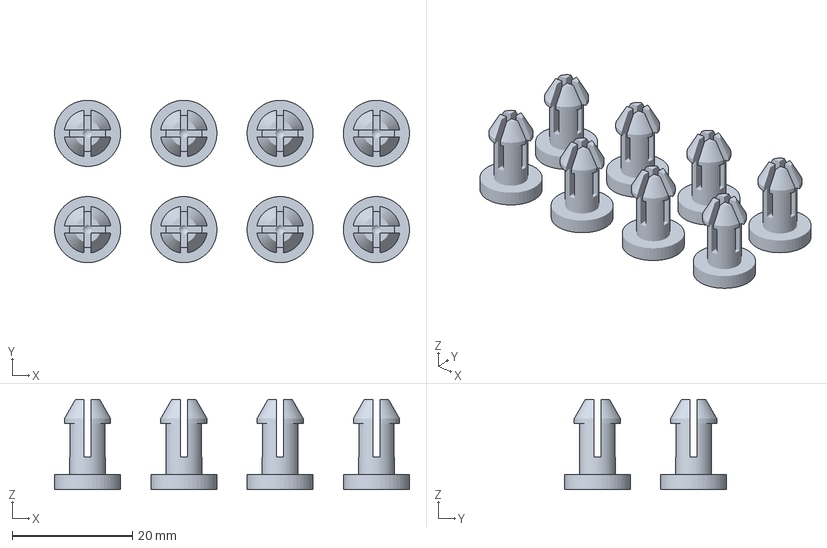
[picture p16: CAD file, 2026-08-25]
ugv_jga25_v2/3MF/08_Chot_Snap_Pin_Chu_Thap.3mf
59.0 x 27.0 x 15.0 mm

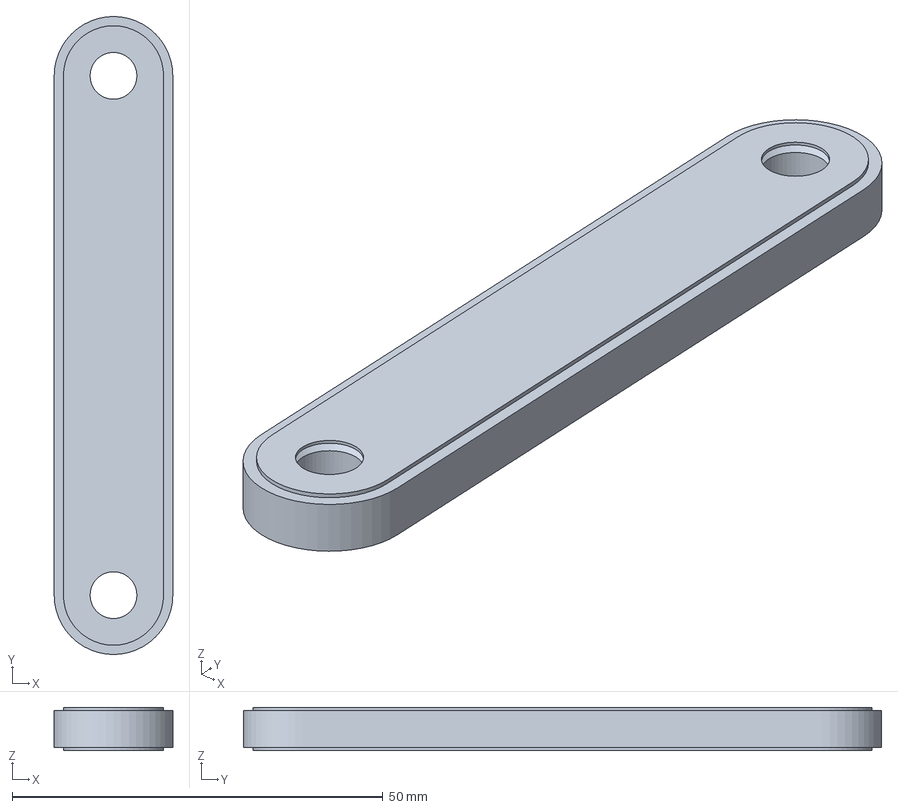
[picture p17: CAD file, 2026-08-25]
ugv_jga25_v2/3MF/04_Thanh_Don_He_Treo.3mf
16.0 x 86.0 x 5.80 mm

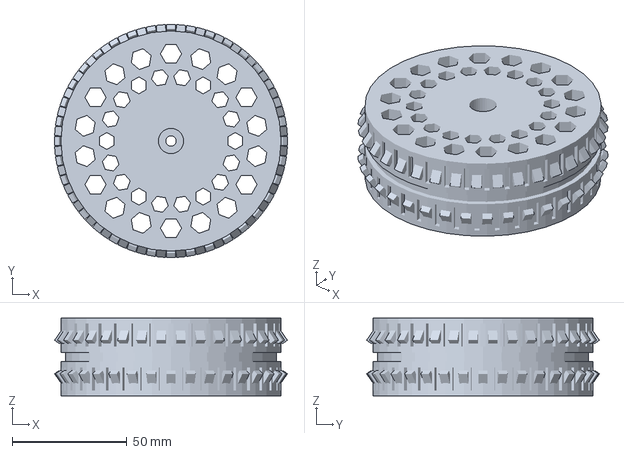
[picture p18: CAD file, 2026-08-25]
ugv_jga25_v2/3MF/05_Banh_Xe_To_Ong.3mf
101.6 x 101.6 x 34.0 mm

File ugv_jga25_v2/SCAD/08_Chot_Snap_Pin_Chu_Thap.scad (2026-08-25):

// ==============================================================================
// 08. CHỐT CÀI XOAY ĐÀN HỒI XẺ RÃNH CHỮ THẬP (CROSS-SLOTTED ROTARY SNAP-PIN)
// BỘ PHẬN IN 3D SỐ 8 - DÙNG CHO CÁC KHỚP XOAY HỆ TREO, BẢN LỀ, PHUỘC NHÚN
// NGUYÊN LÝ:
// 1. THÂN TRỤ TRÒN ĐÚT VÀO LỖ ĐỂ XOAY TỰ DO 360 ĐỘ
// 2. MŨ NẤM CÓ GỜ KHÓA VÀ ĐẦU VÁT CÔN DẪN HƯỚNG ĐỂ ẤN VÀO NHẸ NHÀNG
// 3. XẺ RÃNH CHỮ THẬP (+) TẠO 4 CÁNH ĐÀN HỒI: KHI ẤN VÀO BÓP CỤP LẠI,
//    KHI QUA HẾT LỖ TỰ ĐỘNG BẬT BUNG XÒE RA -> VƯỚNG MŨ KHÓA CHỐNG TUỘT 100%!
// KHÔNG CẦN DÙNG BULÔNG, ỐC VÍT HAY TÁN KIM LOẠI
// VẬT LIỆU TỐT NHẤT: PETG / ABS / NYLON (CÓ ĐỘ DẺO ĐÀN HỒI CAO)
// ==============================================================================
$fn = 48;

module Cross_Slotted_Snap_Pin(
    pin_d     = 6.0,   // Đường kính thân chốt xoay (D=6mm)
    grip_L    = 8.5,   // Chiều dài kẹp qua 2 vách lỗ xoay
    cap_d     = 7.8,   // Đường kính mũ nấm khóa (phình to hơn lỗ 1.8mm)
    cap_L     = 4.0,   // Chiều cao mũ nấm
    slot_w    = 1.2,   // Chiều rộng rãnh xẻ chữ thập (+)
    head_d    = 11.0,  // Đường kính gờ chặn đuôi chốt
    head_t    = 2.5    // Độ dày gờ chặn đuôi
) {
    difference() {
        union() {
            // [1] Gờ chặn đuôi (chống chốt bị lọt qua lỗ)
            cylinder(d = head_d, h = head_t);

            // [2] Thân trụ xoay trơn mượt
            translate([0, 0, head_t])
                cylinder(d = pin_d, h = grip_L);

            // [3] Mũ nấm khóa đầu chốt (Retaining Barb Cap)
            translate([0, 0, head_t + grip_L]) {
                // Gờ khóa vuông giữ chặt mép lỗ
                cylinder(d = cap_d, h = 0.8);
                // Nón vát côn 40 độ dẫn hướng khi đút vào lỗ
                translate([0, 0, 0.8])
                    cylinder(d1 = cap_d, d2 = pin_d - 1.8, h = cap_L - 0.8);
            }
        }

        // [4] Khoét 2 rãnh xẻ chữ thập vuông góc (+) tạo 4 cánh đàn hồi
        translate([0, 0, head_t + grip_L * 0.4 + (grip_L * 0.6 + cap_L)/2]) {
            cube([slot_w, cap_d + 4.0, grip_L * 0.6 + cap_L + 1.0], center = true);
            cube([cap_d + 4.0, slot_w, grip_L * 0.6 + cap_L + 1.0], center = true);
        }

        // Lỗ tròn giảm ứng suất tập trung ở gốc rãnh chữ thập (chống nứt gãy)
        translate([0, 0, head_t + grip_L * 0.4])
            sphere(d = slot_w * 1.5);
    }
}

print_mode = "batch"; // "single" = Xem/in 1 chốt, "batch" = In cả cụm 8 chốt

if (print_mode == "single") {
    Cross_Slotted_Snap_Pin();
} else {
    // XẾP 8 CHỐT CÀI TRÊN BÀN IN Z = 0 ĐỂ IN 1 LẦN CHO CẢ 4 BÁNH XE
    for (row = [0, 1]) {
        for (col = [0, 1, 2, 3]) {
            translate([col * 16.0 - 24.0, row * 16.0 - 8.0, 0])
                Cross_Slotted_Snap_Pin();
        }
    }
}

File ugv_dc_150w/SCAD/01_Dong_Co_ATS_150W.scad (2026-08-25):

// ==============================================================================
// 01. ĐỘNG CƠ DC ATS_MOTOR 150W (ZY6812 / MY6812) & GÁ ĐỠ HEAVY-DUTY KIỂU JGA25
// FILE DUY NHẤT (ALL-IN-ONE): ĐỘNG CƠ + GÁ ĐỠ ÔM THÂN + BU-LÔNG M5 + PULY 3M
// ==============================================================================
// MÀU SẮC CHUẨN THỰC TẾ:
// - Thân động cơ: Đen bóng kim loại nguyên bản (Black Steel)
// - 2 Nắp bích trước/sau & Gờ bạc đạn: Nhôm phay sáng màu bạc (Silver Aluminum)
// - Gá đỡ động cơ: Nhựa in 3D màu đen nhám kỹ thuật (Matte Black PETG)
// - Puly đai 3M: Màu cam thể thao / Nhôm anot (Orange/Anodized)
// - 3 Bu-lông M5: Thép mạ kẽm màu vàng (Zinc-plated Gold)
// ==============================================================================

$fn = 60;

// ==============================================================================
// 1. THÔNG SỐ HÌNH HỌC ĐỘNG CƠ ATS 150W (ZY6812 / MY6812)
// ==============================================================================
MOTOR_D           = 68.0;   // Đường kính thân kim loại motor (mm)
MOTOR_L           = 89.0;   // Chiều dài thân vỏ kim loại (mm)
FRONT_CAP_L       = 6.0;    // Chiều dày nắp nhôm trước (mm)
REAR_CAP_L        = 6.0;    // Chiều dày nắp nhôm sau (mm)

FRONT_BOSS_D      = 29.5;   // Gờ định vị bạc đạn trước (mm)
FRONT_BOSS_H      = 3.5;    // Độ nhô gờ trước (mm)

REAR_BOSS_D       = 30.0;   // Gờ bạc đạn đuôi sau (mm)
REAR_BOSS_H       = 5.0;    // Độ nhô gờ sau (mm)

SHAFT_D           = 8.0;    // Đường kính cốt trục ra (mm)
SHAFT_L           = 22.0;   // Chiều dài trục nhô ra ngoài (mm)
SHAFT_FLAT_DEPTH  = 0.8;    // Độ sâu vát D (chiều dày còn lại 7.2mm)
SHAFT_FLAT_L      = 16.0;   // Chiều dài đoạn vát phẳng (mm)

// 3 Lỗ bắt ốc mặt bích tam giác đều 120°
MOUNT_PITCH       = 35.6;   // Khoảng cách giữa 2 lỗ kề nhau (mm)
MOUNT_RADIUS      = 20.55;  // Bán kính từ tâm trục ra mỗi lỗ (PCD = 41.1mm)
MOUNT_HOLE_D      = 4.2;    // Đường kính lỗ ren M5 (mm)
MOUNT_HOLE_DEPTH  = 8.0;    // Độ sâu lỗ ren (mm)

// ==============================================================================
// 2. THÔNG SỐ GÁ ĐỠ HEAVY-DUTY (BẢN GÁ Ở TRÊN - KHE HỞ IN 3D CHỐNG KẸT)
// ==============================================================================
MOTOR_BORE_D      = 70.0;   // Đường kính khoét lòng vòm (70mm so với motor 68mm -> hở 1.0mm mỗi bên, chống kẹt in 3D)
BRACKET_WALL_T    = 4.5;    // Độ dày vách vòm ôm (4.5mm)
OUTER_R           = MOTOR_BORE_D/2 + BRACKET_WALL_T; // Bán kính ngoài vòm = 39.5mm
SLEEVE_L          = 52.0;   // Chiều dài vòm ôm thân motor (mm)

BASE_PLATE_W      = 82.0;   // Bề rộng bản gá trên (mm)
BASE_PLATE_L      = 52.0;   // Chiều dài bản gá bắt sàn (bằng chiều dài vòm = 52mm phẳng phiu)
BASE_PLATE_T      = 5.0;    // Độ dày bản gá bắt sàn (5mm)

MOTOR_CENTER_H    = 42.0;   // Khoảng cách từ tâm trục motor lên mặt dưới bản gá trên (mm)
TOP_Z             = MOTOR_CENTER_H; // Cao độ mặt dưới bản gá trên (Z = +42mm)

// ==============================================================================
// 3. MODULE CHI TIẾT ĐỘNG CƠ ATS 150W (MÀU ĐEN BÓNG THÉP NGUYÊN BẢN)
// ==============================================================================
module Part_Dong_Co_150W() {
    difference() {
        union() {
            // [A] Toàn bộ thân vỏ thép đen bóng (100% Solid Black Steel)
            color([0.08, 0.08, 0.10])
            translate([-MOTOR_L + REAR_CAP_L, 0, 0])
            rotate([0, 90, 0])
            cylinder(d = MOTOR_D, h = MOTOR_L - FRONT_CAP_L - REAR_CAP_L);

            // [B] Nắp nhôm sau (Màu nhôm phay sáng)
            color([0.78, 0.80, 0.82])
            translate([-MOTOR_L, 0, 0])
            rotate([0, 90, 0])
            cylinder(d = MOTOR_D, h = REAR_CAP_L);

            // Gờ bạc đạn sau
            color([0.72, 0.74, 0.76])
            translate([-MOTOR_L - REAR_BOSS_H, 0, 0])
            rotate([0, 90, 0])
            cylinder(d = REAR_BOSS_D, h = REAR_BOSS_H);

            // [C] Nắp bích nhôm trước (Màu nhôm phay sáng)
            color([0.78, 0.80, 0.82])
            translate([-FRONT_CAP_L, 0, 0])
            rotate([0, 90, 0])
            cylinder(d = MOTOR_D, h = FRONT_CAP_L);

            // Gờ bạc đạn trước
            color([0.72, 0.74, 0.76])
            rotate([0, 90, 0])
            cylinder(d = FRONT_BOSS_D, h = FRONT_BOSS_H);

            // [D] Trục thép chữ D (Inox sáng bóng)
            color([0.88, 0.90, 0.92])
            rotate([0, 90, 0])
            difference() {
                cylinder(d = SHAFT_D, h = SHAFT_L);
                // Vát D
                translate([-SHAFT_D, SHAFT_D/2 - SHAFT_FLAT_DEPTH, SHAFT_L - SHAFT_FLAT_L])
                cube([SHAFT_D * 2, SHAFT_D, SHAFT_FLAT_L + 1]);
            }
        }

        // [E] 3 Lỗ ren M5 mặt bích tam giác đều 120° (90°, 210°, 330°)
        for (ang = [90, 210, 330]) {
            translate([-MOUNT_HOLE_DEPTH + 0.1, MOUNT_RADIUS * cos(ang), MOUNT_RADIUS * sin(ang)])
            rotate([0, 90, 0])
            cylinder(d = MOUNT_HOLE_D, h = MOUNT_HOLE_DEPTH + 1);
        }

        // [F] 2 Vít chìm giữ nắp máy (0° và 180°)
        for (ang = [0, 180]) {
            translate([-3, 24 * cos(ang), 24 * sin(ang)])
            rotate([0, 90, 0])
            cylinder(d = 3.5, h = 4);
        }
    }
}

// ==============================================================================
// 4. MODULE GÁ ĐỠ ĐỘNG CƠ HEAVY-DUTY (MÀU XANH LÁ CÂY IN 3D)
// ==============================================================================
module Part_Ga_Do_Kieu_JGA25() {
    color([0.18, 0.72, 0.28]) { // Màu xanh lá cây nổi bật (Vibrant Green)
        difference() {
            union() {

                // [A] Mặt đứng trước bắt mặt bích motor (Dày 5mm)
                translate([0, -BASE_PLATE_W/2, -OUTER_R])
                cube([5.0, BASE_PLATE_W, (TOP_Z + BASE_PLATE_T) - (-OUTER_R)]);

                // [B] Vòm ống trụ ôm thân motor (Tâm Z = 0, Dài 52mm)
                translate([-SLEEVE_L, 0, 0])
                rotate([0, 90, 0])
                cylinder(r = OUTER_R, h = SLEEVE_L);

                // [C] Bản gá bắt sàn ở TRÊN CÙNG (Dày 5mm, Z = TOP_Z đến TOP_Z + BASE_PLATE_T)
                translate([-BASE_PLATE_L, -BASE_PLATE_W/2, TOP_Z])
                cube([BASE_PLATE_L, BASE_PLATE_W, BASE_PLATE_T]);

                // [D] Khối gân liên kết đặc kết nối vòm ôm lên bản gá trên (Liền khối siêu cứng)
                translate([-BASE_PLATE_L, -BASE_PLATE_W/2, 0])
                cube([BASE_PLATE_L, BASE_PLATE_W, TOP_Z]);
            }

            // --- CÁC PHẦN KHOÉT RỖNG (DIFFERENCE) ---

            // 1. LÒNG VÒM ÔM THÂN MOTOR (D = 70.0mm -> Khe hở 1.0mm mỗi bên, KHÔNG BỊ KẸT IN 3D)
            translate([-SLEEVE_L - 1, 0, 0])
            rotate([0, 90, 0]) {
                cylinder(d = MOTOR_BORE_D, h = SLEEVE_L + 2);
                // Vát mép miệng sau (Chamfer Lead-in rộng 73mm) giúp đút motor nhẹ nhàng
                translate([0, 0, 0])
                cylinder(d1 = MOTOR_BORE_D + 3.0, d2 = MOTOR_BORE_D, h = 4.0);
            }

            // 2. Lỗ tròn thoát gờ bạc đạn tâm trước
            translate([-2, 0, 0])
            rotate([0, 90, 0])
            cylinder(d = 31.0, h = 10);

            // 3. 3 Rãnh hạt đậu tam giác đều 120° bắt bu-lông M5 (Góc 90°, 210°, 330°)
            for (ang = [90, 210, 330]) {
                hull() {
                    translate([-2, 18.5 * cos(ang), 18.5 * sin(ang)])
                    rotate([0, 90, 0])
                    cylinder(d = 5.5, h = 10);

                    translate([-2, 22.5 * cos(ang), 22.5 * sin(ang)])
                    rotate([0, 90, 0])
                    cylinder(d = 5.5, h = 10);
                }
            }

            // 4. Khoét khe hở giải nhiệt và giảm trọng lượng ở đáy vòm
            translate([-SLEEVE_L - 1, -MOTOR_BORE_D/2 + 8, -OUTER_R - 1])
            cube([SLEEVE_L + 2, MOTOR_BORE_D - 16, 5]);

            // 5. 4 Lỗ bắt bu-lông M6 trên BẢN GÁ TRÊN (Bắt treo lên khung sàn gầm xe)
            for (by = [-BASE_PLATE_W/2 + 12, BASE_PLATE_W/2 - 12]) {
                for (bx = [-12, -BASE_PLATE_L + 12]) {
                    translate([bx, by, TOP_Z - 1])
                    cylinder(d = 6.5, h = BASE_PLATE_T + 2);
                    // Vát chìm nón đầu ốc M6
                    translate([bx, by, TOP_Z + BASE_PLATE_T - 1.5])
                    cylinder(d1 = 6.5, d2 = 11.5, h = 2.0);
                }
            }

            // 6. Lỗ thoát khí giải nhiệt trên đỉnh bản gá
            translate([-SLEEVE_L/2, 0, 0])
            cylinder(d = 16.0, h = TOP_Z + BASE_PLATE_T + 5);
        }
    }
}
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

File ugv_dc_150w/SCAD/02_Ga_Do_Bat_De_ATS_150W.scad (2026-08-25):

// ==============================================================================
// 02. GÁ ĐỠ ĐỘNG CƠ ATS 150W HEAVY-DUTY (KIỂU ÔM THÂN JGA25 - BẢN GÁ Ở TRÊN)
// PHỤ KIỆN GÁ ĐỘNG CƠ LÊN KHUNG XE UGV / BÀN MÁY TẢI NẶNG
// ==============================================================================
// MÀU SẮC: MÀU XANH LÁ CÂY IN 3D (VIBRANT GREEN)
// ==============================================================================

$fn = 60;

use <01_Dong_Co_ATS_150W.scad>

// Tùy chọn hiển thị
SHOW_MOTOR_PREVIEW = true; // Bật/tắt hiển thị động cơ lắp vào gá

// Module gá đỡ độc lập
module Ga_Do_ATS_150W_Printable() {
    Part_Ga_Do_Kieu_JGA25();
}

// 1. Hiển thị gá đỡ
Ga_Do_ATS_150W_Printable();

// 2. Hiển thị động cơ và ốc đi kèm để kiểm tra độ khớp
if (SHOW_MOTOR_PREVIEW) {
    Part_Dong_Co_150W();
    Part_Bu_Long_M5();
    Part_Puly_Dai_3M();
}

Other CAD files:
ugv_jga25_v2/SCAD/00_UGV_Lap_Rap_Tong_The_v2.scad
ugv_jga25_v1/SCAD/00_UGV_Lap_Rap_Tong_The.scad
ugv_jga25_v1/SCAD/01_Khung_Than_Xe_Lien_Khoi.scad
ugv_jga25_v1/SCAD/02_Nap_Noc_Xe.scad
ugv_jga25_v1/SCAD/03_Ga_Do_Dong_Co.scad
ugv_jga25_v1/SCAD/04_Thanh_Don_He_Treo.scad
ugv_jga25_v1/SCAD/05_Banh_Xe_To_Ong.scad
ugv_jga25_v1/SCAD/06_Phuoc_Giam_Xoc.scad
ugv_jga25_v1/SCAD/07_Tay_Nam_Nap_Noc.scad
ugv_jga25_v1/STL/01_Khung_Than_Xe_Lien_Khoi.stl
ugv_jga25_v1/STL/02_Nap_Noc_Xe.stl
ugv_jga25_v1/STL/03_Ga_Do_Dong_Co.stl
ugv_jga25_v1/STL/04_Thanh_Don_He_Treo.stl
ugv_jga25_v1/STL/05_Banh_Xe_To_Ong.stl
ugv_jga25_v1/STL/06_Phuoc_Giam_Xoc.stl
ugv_jga25_v1/STL/07_Tay_Nam_Nap_Noc.stl
ugv_jga25_v1/STL/08_Chot_Snap_Pin_Chu_Thap.stl
ugv_jga25_v2/SCAD/01_Khung_Than_Xe_Lien_Khoi.scad
ugv_jga25_v2/SCAD/02_Nap_Noc_Xe.scad
ugv_jga25_v2/SCAD/03_Ga_Do_Dong_Co.scad
ugv_jga25_v2/SCAD/04_Thanh_Don_He_Treo.scad
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

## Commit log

2026-08-25 feat(ugv): nang cap he treo khop cau dan hoi snap-fit, tang chieu cao gam noc, chu SUMO dap noi, lo xo day 6.2mm va bo tay cam
    [00_UGV_Lap_Rap_Tong_The.scad, 00_UGV_Lap_Rap_Tong_The_Full_Xe.3mf, 01_Khung_Than_Xe_Lien_Khoi.3mf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]
2026-08-25 fix(ball-stud): lam sach co qua cau loi, bo khoi gan vuong thua va toi uu mieng chen cau dan hoi
    [00_UGV_Lap_Rap_Tong_The.scad, 01_Khung_Than_Xe_Lien_Khoi.scad, 03_Ga_Do_Dong_Co.3mf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]
2026-08-25 sync: dong bo toan dien tat ca cac file chi tiet tu 01 den 08 theo chuan file tong the 00
    [01_Khung_Than_Xe_Lien_Khoi.3mf, 01_Khung_Than_Xe_Lien_Khoi.stl, 02_Nap_Noc_Xe.3mf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]
2026-08-25 fix(ball-mount): sua chan de qua cau loi bang hull phang tiep xuc 100%, co thon D=5mm va xuat 3 chi tiet phuoc gom lo xo day
    [00_UGV_Lap_Rap_Tong_The.scad, 01_Khung_Than_Xe_Lien_Khoi.3mf, 01_Khung_Than_Xe_Lien_Khoi.scad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]
2026-08-25 feat: restructure into multi-platform UGV monorepo (ugv_jga25, ugv_dc_150w, ugv_my1016z_250w)
    [00_UGV_Lap_Rap_Tong_The.scad, 00_UGV_Lap_Rap_Tong_The_Full_Xe.3mf, 01_Dong_Co_ATS_150W.scad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]
2026-08-25 feat(jga25): add 00_UGV_Lap_Rap_Tong_The_v2.scad with dynamic suspension & LiDAR mounts
    [00_UGV_Lap_Rap_Tong_The_v2.scad]
2026-08-25 feat(v2): split monolithic chassis into 5 colored print-ready modules for 320x390 bed
    [00_UGV_Lap_Rap_Tong_The_v2.scad]
2026-08-25 feat(v2): add mechanical interlocking mechanisms (vertical dovetails, captive M3 nut pockets, slide-in fender rails)
    [00_UGV_Lap_Rap_Tong_The_v2.scad]
2026-08-25 fix(roof): remove circular lidar mount disk and holes from roof canopy
    [00_UGV_Lap_Rap_Tong_The_v2.scad]
2026-08-25 refactor: split jga25 into ugv_jga25_v1 (monolithic) and ugv_jga25_v2 (modular)
    [00_UGV_Lap_Rap_Tong_The.scad, 00_UGV_Lap_Rap_Tong_The_Full_Xe.3mf, 00_UGV_Lap_Rap_Tong_The_v2.scad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]
